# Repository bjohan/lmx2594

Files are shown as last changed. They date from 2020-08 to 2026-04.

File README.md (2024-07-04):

# lmx2594
Test board for lmx2594. The PCB is connected to an Arduino nano which then can be controlled from a PC. The Arduino can be programmed so that the PLL always starts with a certain frequency. It is also possible to change frequency dynamically.

# PCB
Current version of PCB in pcb/lmx2594_v2/

# Arduino sketch
In lmx2594NewSketch/

# Python library commandline tool
In py/ 
```
/lmx2594cmd2.py --help
usage: lmx2594.py [-h] [-f FREQUENCY] [-r REFERENCE] [-mo MASH_ORDER] [-m] [-l] port

Program for controlling lmx2594 pll

positional arguments:
  port                  For instance /dev/ttyUSB0

options:
  -h, --help            show this help message and exit
  -f FREQUENCY, --frequency FREQUENCY
                        Set frequency
  -r REFERENCE, --reference REFERENCE
                        Reference frequency
  -mo MASH_ORDER, --mash-order MASH_ORDER
                        Order of delta sigma
  -m, --macro           Record macro while setting frequency that will be executed at boot. This means that the device will set the specified frequency during power on even without a
                        computer
  -l, --locked          Check lock status

Have fun!
```

Example:

Program arduino so it always starts at 1296MHz with 10MHz reference
```
./lmx2594cmd2.py /dev/ttyUSB0 -r 10e6 -f 1296e6 -m
```

Example:

Set the frequency to 144MHz with 10MHz reference
```
./lmx2594cmd2.py /dev/ttyUSB0 -r 10e6 -f 144e6
```

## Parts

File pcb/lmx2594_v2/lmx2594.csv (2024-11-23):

Source: | /home/bjohan/git_wd/lmx2594/pcb/lmx2594_v2/lmx2594.sch
Date: | lör 23 nov 2024 11:15:43
Tool: | Eeschema 7.0.11+dfsg-1build4
Generator: | /usr/share/kicad/plugins/bom_csv_grouped_by_value_with_fp.py
Component Count: | 108
Ref | Qnty | Value | Cmp name | Footprint | Description | Vendor | DNP
C1, C4, C5, C7, C10, C13, C15 | 7 | 10u | C | Capacitors_SMD:C_1210 | Unpolarized capacitor
C2, C3, C6, C8, C9, C11, C12, C14, C19, C40, C41, C42, C43, C59 | 14 | 100n | C | Capacitors_SMD:C_0603 | Unpolarized capacitor
C16, C21, C22, C23, C24, C25, C32, C35, C38, C44, C45 | 11 | 1u | C | Capacitors_SMD:C_0603 | Unpolarized capacitor
C17, C20, C51, C53 | 4 | 10p | C | Capacitors_SMD:C_0402 | Unpolarized capacitor
C18, C26, C27, C33, C50, C52, C56, C57 | 8 | 100n | C | Capacitors_SMD:C_0402 | Unpolarized capacitor
C28 | 1 | 1.8n | C | Capacitors_SMD:C_0603 | Unpolarized capacitor
C29 | 1 | 0p | C | Capacitors_SMD:C_0603 | Unpolarized capacitor
C30 | 1 | 68n | C | Capacitors_SMD:C_0603 | Unpolarized capacitor
C31 | 1 | 390p | C | Capacitors_SMD:C_0603 | Unpolarized capacitor
C34, C36, C37, C39 | 4 | 10u | C | Capacitors_SMD:C_0603 | Unpolarized capacitor
C46 | 1 | 10u-1000u | C | Capacitors_SMD:C_1210_HandSoldering | Unpolarized capacitor
C55, C58 | 2 | 100p | C | Capacitors_SMD:C_0402 | Unpolarized capacitor
D1, D2, D3 | 3 | LED | LED | LEDs:LED_0805_HandSoldering | Light emitting diode
J1, J2, J4, J5, J7, J9 | 6 | Conn_Coaxial | Conn_Coaxial | sch:sma_endlaunch | coaxial connector (BNC, SMA, SMB, SMC, Cinch/RCA, LEMO, ...)
J3 | 1 | Conn_01x13_Male | Conn_01x13_Male-Connector | Connectors_Molex:Molex_KK-6410-13_13x2.54mm_Straight
L1, L3, L5 | 3 | 33u | L_Core_Ferrite-Device | Inductors_NEOSID:Neosid_Inductor_Ms95
L2, L4 | 2 | 10n | L_Core_Ferrite-Device | Capacitors_SMD:C_0402
L7, L8 | 2 | 18n | L | Capacitors_SMD:C_0402 | Inductor
R1, R2, R6, R7, R10, R15, R24, R25, R26, R27 | 10 | 0 | R | Capacitors_SMD:C_0603 | Resistor
R3, R8 | 2 | 50 | R | Capacitors_SMD:C_0603 | Resistor
R4, R9 | 2 | 150 | R | Capacitors_SMD:C_0603 | Resistor
R5 | 1 | 1k | R | Capacitors_SMD:C_0603 | Resistor
R11, R12, R13, R16, R18, R19, R20, R22 | 8 | 50 | R | Resistors_SMD:R_0402 | Resistor
R14 | 1 | 18 | R | Capacitors_SMD:C_0603 | Resistor
R17, R28, R29 | 3 | 68 | R | Capacitors_SMD:C_0603 | Resistor
R21 | 1 | 100 | R | Capacitors_SMD:C_0603 | Resistor
R23 | 1 | 10K | R | Capacitors_SMD:C_0603 | Resistor
U1 | 1 | LM7809_TO220 | LM7809_TO220 | Package_TO_SOT_THT:TO-220-3_Vertical | Positive 1A 35V Linear Regulator, Fixed Output 9V, TO-220
U2 | 1 | VS_500 | VS_500 | Oscillators:Oscillator_SMD_Fordahl_DFAS1-6pin_14.8x9.1mm
U3 | 1 | lmx254 | lmx254 | Housings_DFN_QFN:Texas_PVQFN-N40
U4 | 1 | L7805 | L7805 | Power_Integrations:TO-220 | Positive 1.5A 35V Linear Regulator, Fixed Output 5V, TO-220/TO-263/TO-252
U5 | 1 | ADP7158 | ADP7158 | Housings_SOIC:SOIC-8-1EP_3.9x4.9mm_Pitch1.27mm
U6, U7 | 2 | GRF3042 | GRF3042 | Housings_DFN_QFN:DFN-6-1EP_2x2mm_Pitch0.5mm

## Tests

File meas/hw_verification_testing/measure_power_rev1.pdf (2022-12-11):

## measure_power

May 23, 2022

[2]: import sys
sys.path.append("gpib_instrument_control/") import lmx2594
import gpib_instrument_control.hp_3478a
import gpib_instrument_control.pm_1038

meter = gpib_instrument_control.hp_3478a.Hp3478A()
pm = gpib_instrument_control.pm_1038.Pm1038(None, meter, None,␣ ↪"pm11-0674_correctionFactors.mat")

lmx = lmx2594.Lmx2594('/dev/ttyUSB0', 320e6)

lmx.enableLockDetect(True)
print("Is locked?", lmx.isLocked()) print(pm.readChannelB(50e6))

Created LMX object wit fosc 320.0 Resetting LMX
Applying config
Is locked: True
Is locked? True
-7.598000000000001

[16]: import numpy as np
import matplotlib.pyplot as plt
import time
%matplotlib inline
plt.rcParams['figure.figsize'] = [15, 10]

def powerSweep(frange):
ampl = []
lmx.setFrequency(frange[0]) time.sleep(1)
for f in frange:
lmx.setFrequency(f)
ampl.append(pm.readChannelB(f)) return ampl

#frange = np.linspace(1e9, 15e9, 30) #plt.plot(frange, ampl)

[18]: frange = np.linspace(10e9, 15e9, 1500) amplRedA = powerSweep(frange) plt.plot(frange, amplRedA, label='redA') plt.grid(True)
plt.legend()
plt.title('Output power vs frequency') plt.ylabel('Output power [dBm]') plt.xlabel('frequency [Hz]')

[18]: Text(0.5, 0, 'frequency [Hz]')

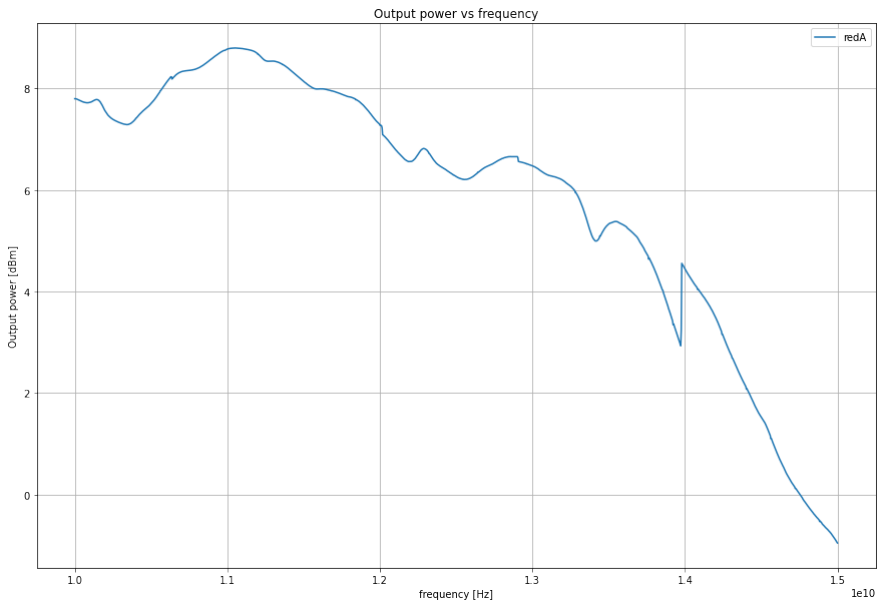
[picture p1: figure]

[20]: frange = np.linspace(10e9, 15e9, 1500) amplRedB = powerSweep(frange) plt.plot(frange, amplRedB, label='redB') plt.grid(True)
plt.legend()
plt.title('Output power vs frequency') plt.ylabel('Output power [dBm]') plt.xlabel('frequency [Hz]')

[20]: Text(0.5, 0, 'frequency [Hz]')

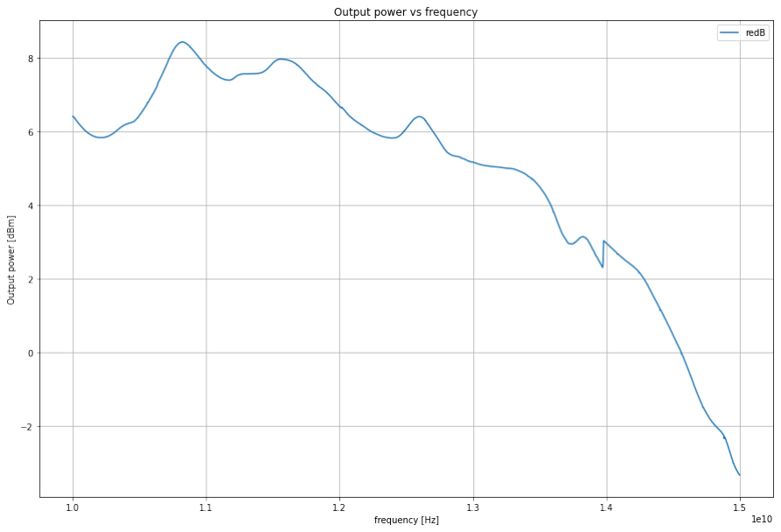
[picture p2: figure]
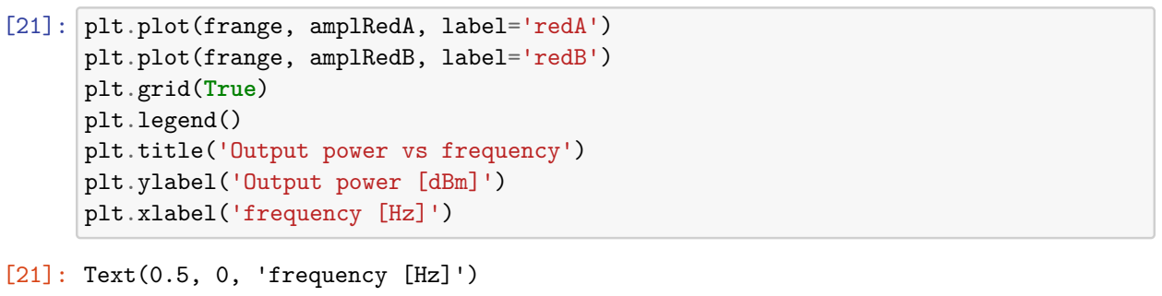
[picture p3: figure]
[21]: plt.plot(frange, amplRedA, label='redA') plt.plot(frange, amplRedB, label='redB') plt.grid(True) plt.legend() plt.title('Output power vs frequency') plt.ylabel('Output power [dBm]') plt.xlabel('frequency [Hz]'); [21]: Text(0.5, 0, 'frequency [Hz]')

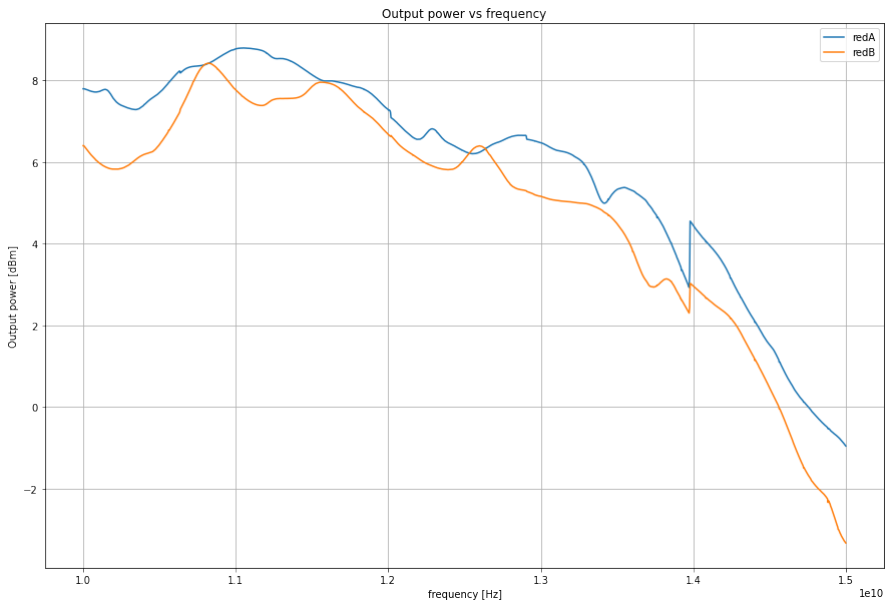
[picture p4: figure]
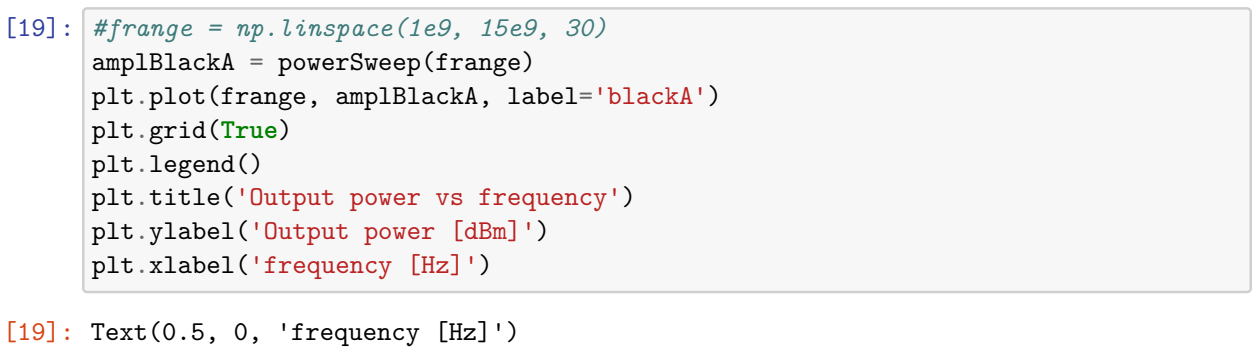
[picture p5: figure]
amplBlackA = powerSweep(frange) plt.plot(frange, amplBlackA, label='blackA') plt.grid(True) plt.legend() plt.title('Output power vs frequency') plt.ylabel('Output power [dBm]') plt.xlabel('frequency [Hz]'); [19]: Text(0.5, 0, 'frequency [Hz]')

[19]: #frange = np.linspace(1e9, 15e9, 30)

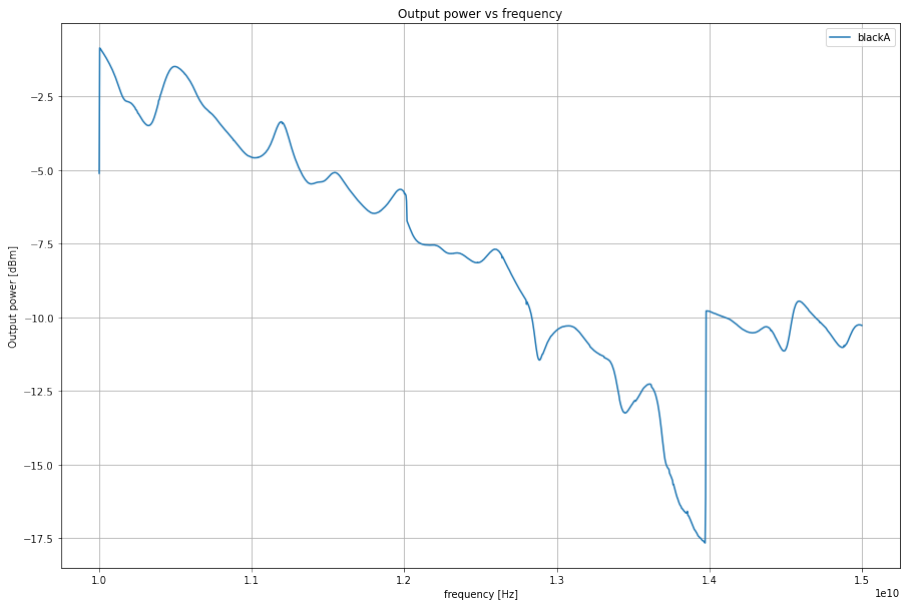
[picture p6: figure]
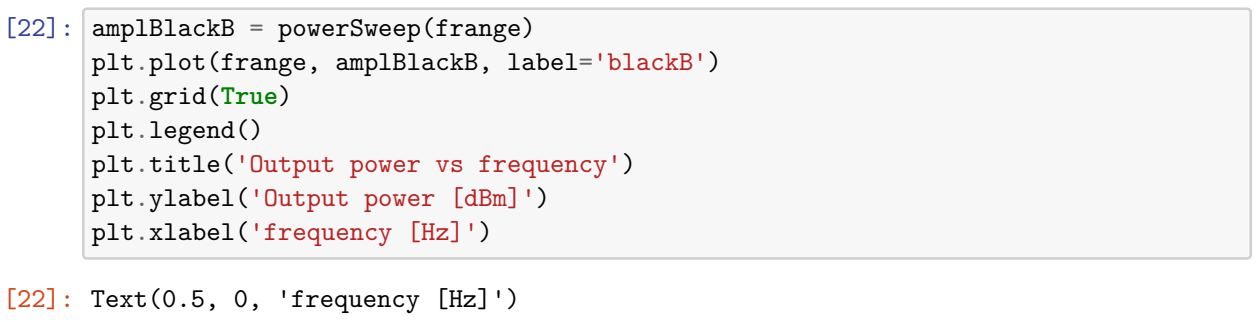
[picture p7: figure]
[22]: amplBlackB = powerSweep(frange) plt.plot(frange, amplBlackB, label='blackB') plt.grid(True) plt.legend() plt.title('Output power vs frequency') plt.ylabel('Output power [dBm]') plt.xlabel('frequency [Hz]'); [22]: Text(0.5, 0, 'frequency [Hz]')

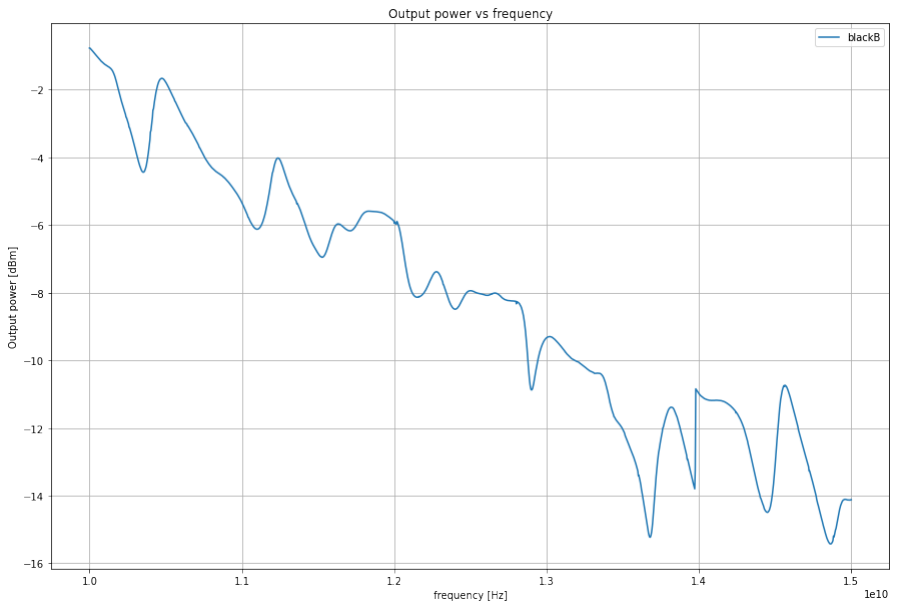
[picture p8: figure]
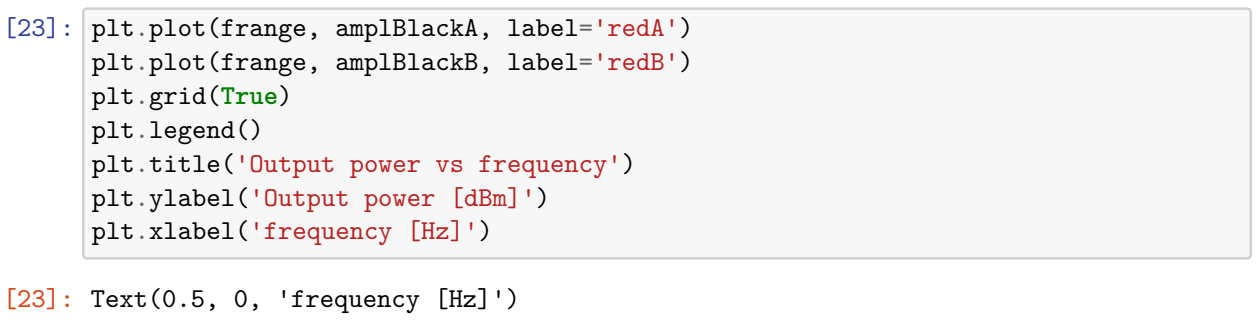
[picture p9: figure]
[23]: plt.plot(frange, amplBlackA, label='redA') plt.plot(frange, amplBlackB, label='redB') plt.grid(True) plt.legend() plt.title('Output power vs frequency') plt.ylabel('Output power [dBm]') plt.xlabel('frequency [Hz]'); [23]: Text(0.5, 0, 'frequency [Hz]')

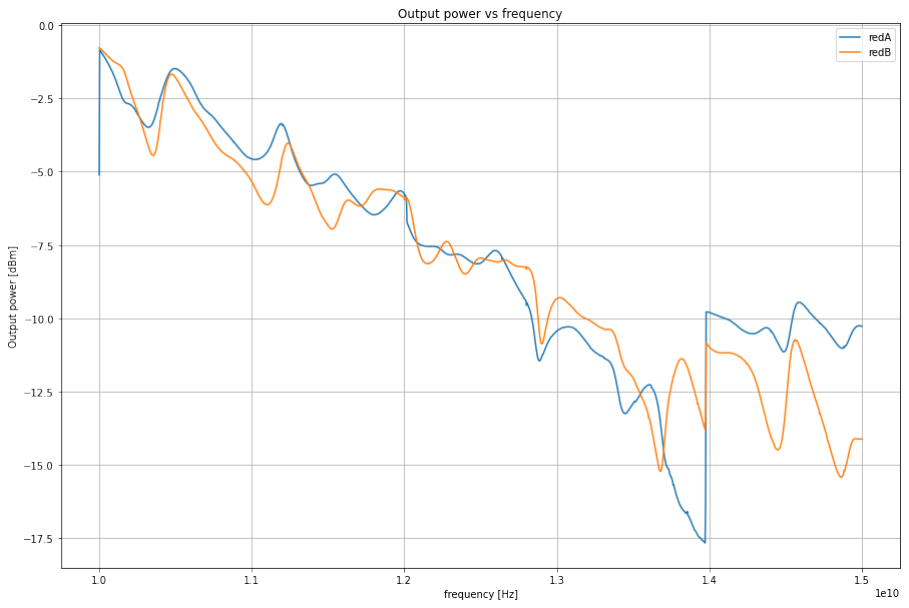
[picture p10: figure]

[25]: import scipy.io as sio

sm = {'f':frange,
'redA': amplRedA,
'redB': amplRedB,
'redA': amplBlackA,
'redB': amplBlackB,
}

sio.savemat('amplitude_data.mat', sm)

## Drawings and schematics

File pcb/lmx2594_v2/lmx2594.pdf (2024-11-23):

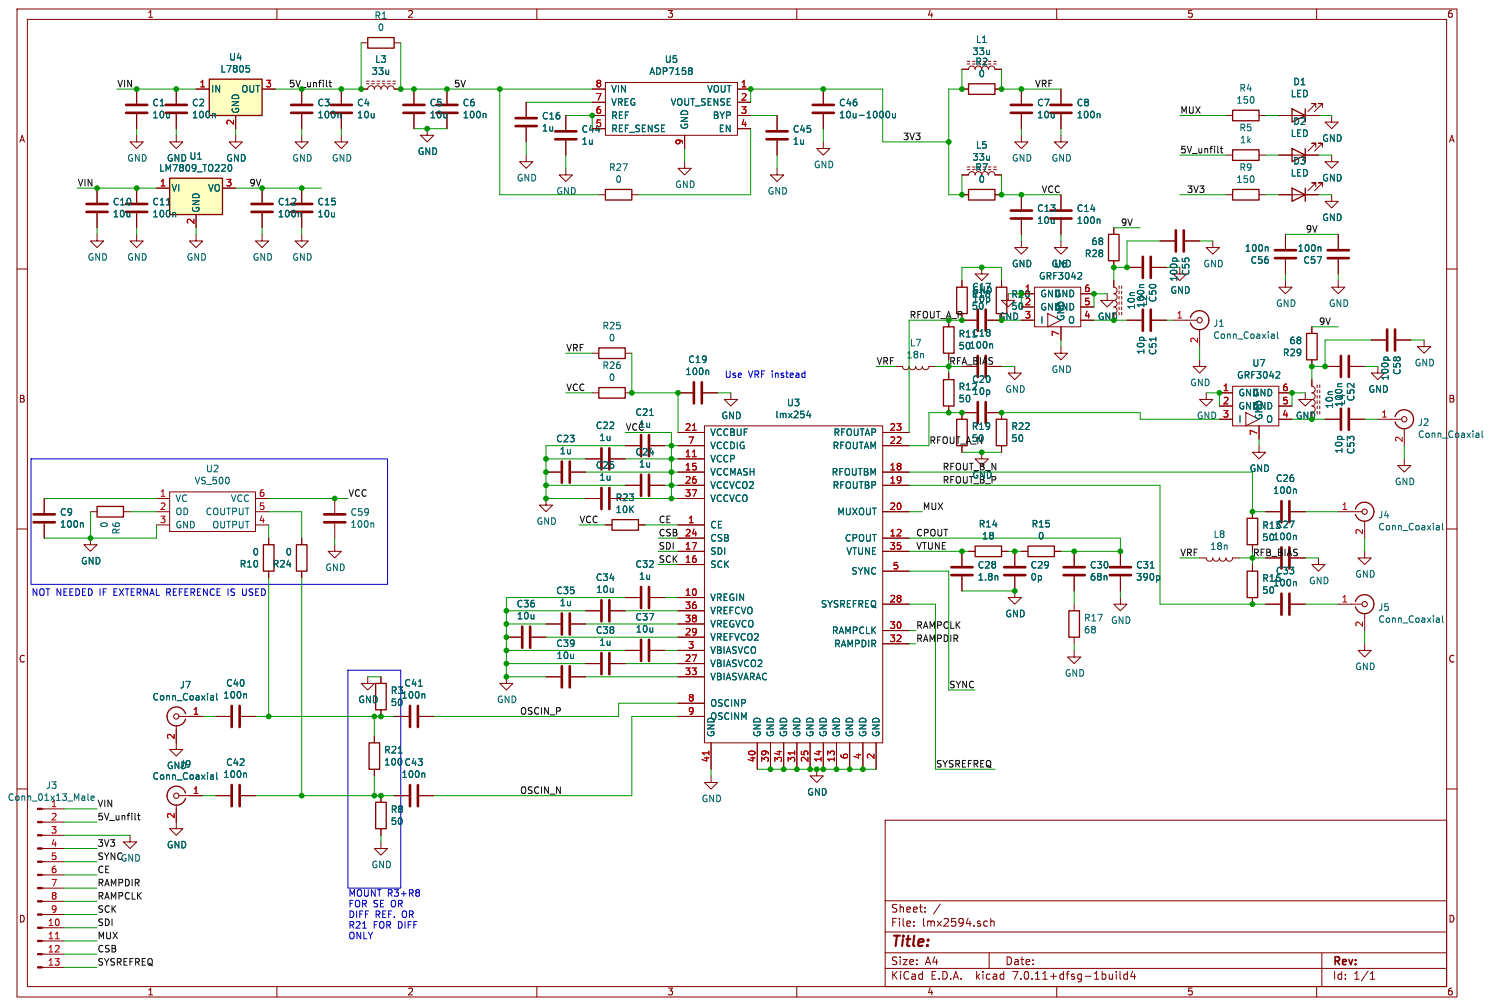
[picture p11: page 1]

2 MUXOUT 20 VCCBUF 21 RFOUTAM 22 RFOUTAP 23 CSB 24 GND 25 VCCVCO2 26 VBIASVCO2 27 SYSREFREQ 28 VREFVCO2 29 VBIASVCO 3 RAMPCLK 30 GND 31 RAMPDIR 32 VBIASVARAC 33 GND 34 VTUNE 35 VREFCVO 36 VCCVCO 37 VREGVCO 38 GND 39 GND

6 VCCDIG 7 OSCINP 8 OSCINM 9 GND

4 GND 40 GND 41 SYNC 5 GND

Id: 1/1 Title: File: lmx2594.sch Sheet: /

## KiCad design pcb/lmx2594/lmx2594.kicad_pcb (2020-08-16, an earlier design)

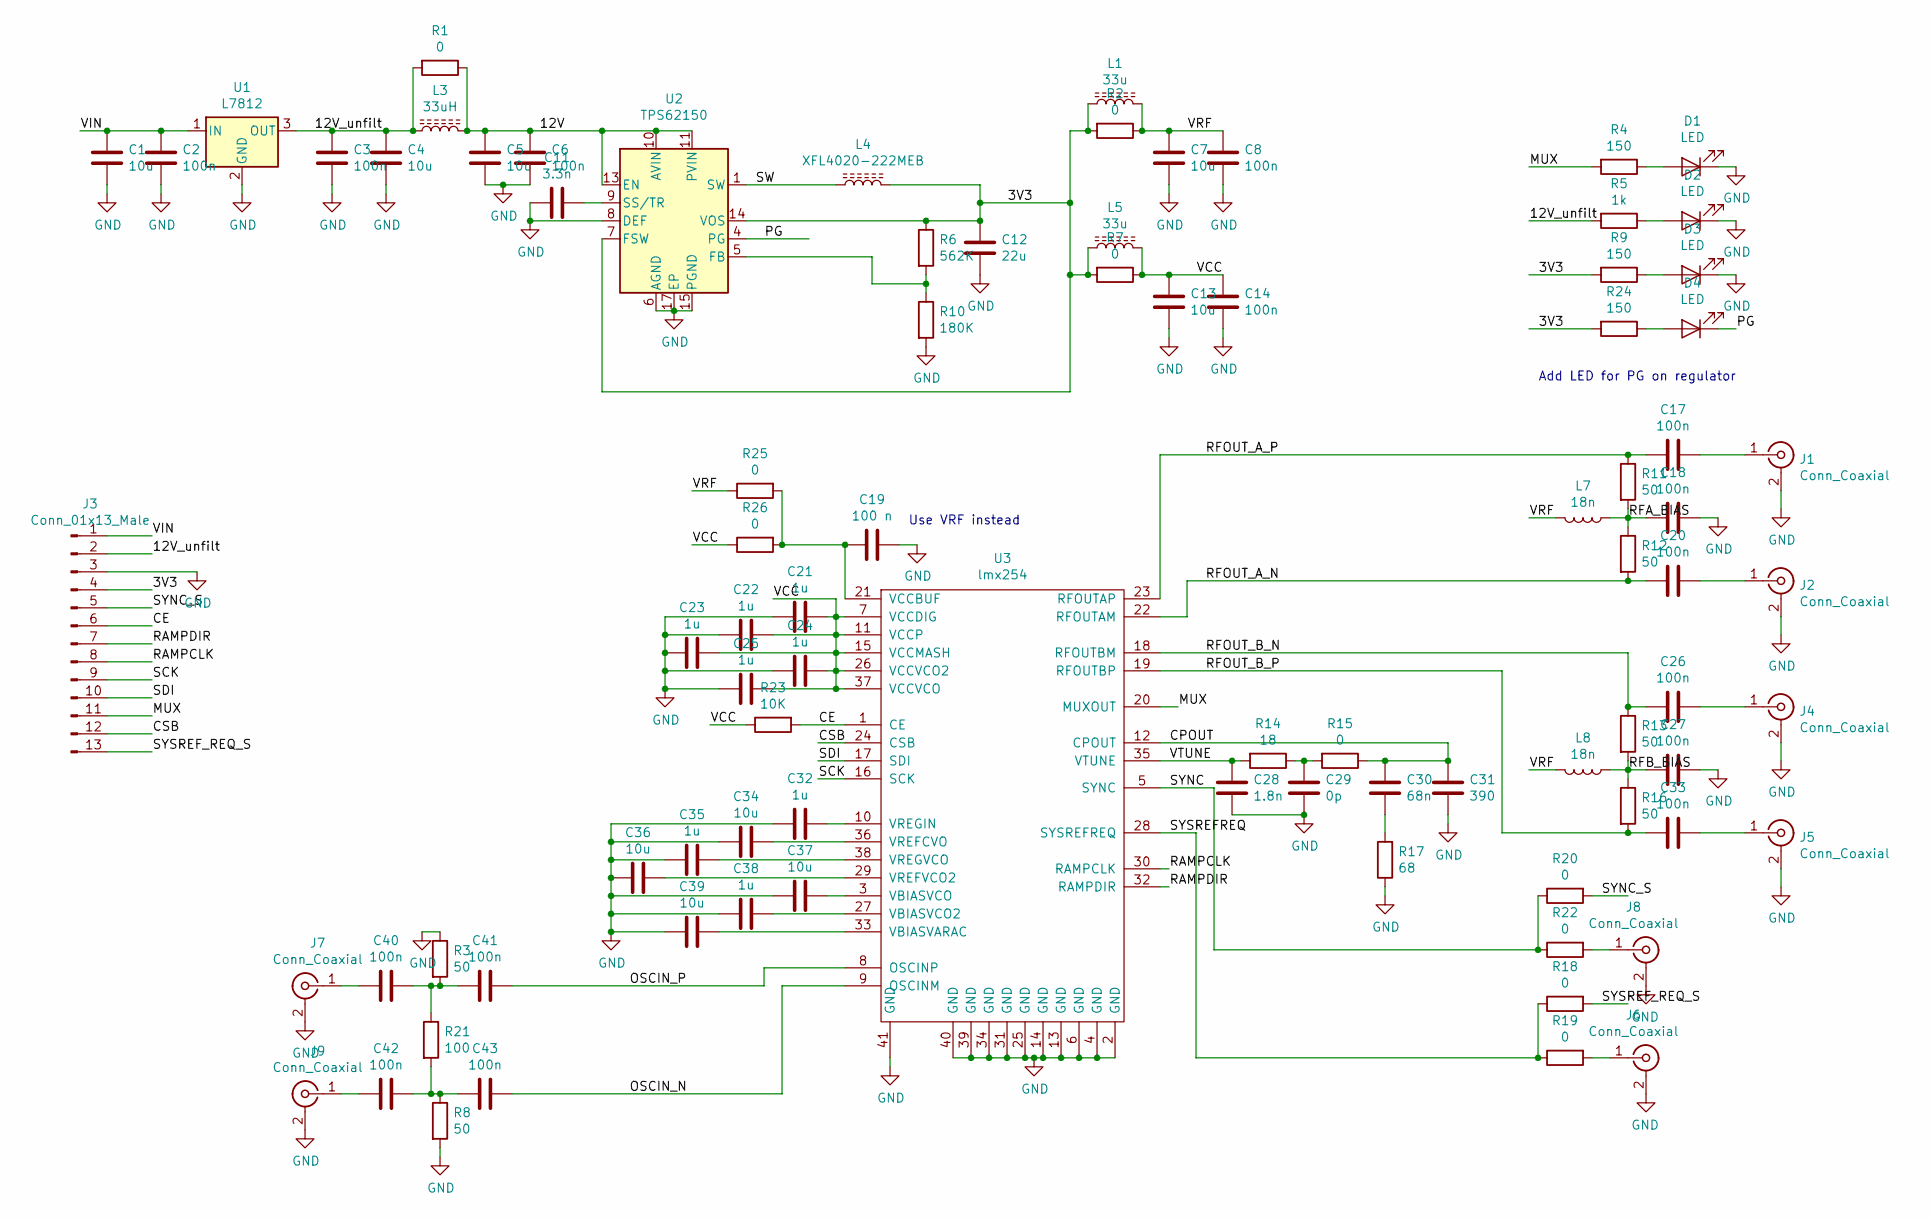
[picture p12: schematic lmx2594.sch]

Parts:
C1, C4, C5: 10u; C_1210_HandSoldering
C2, C3, C6, C8, C14, C17, C18, C20, C26, C27, C33, C40, C41, C42, C43: 100n; C_0603
C7, C13, C34, C36, C37, C39: 10u; C_0603
C11: 3.3n; C_0603
C12: 22u; C_0603
C19: 100 n; C_0603
C21, C22, C23, C24, C25, C32, C35, C38: 1u; C_0603
C28: 1.8n; C_0603
C29: 0p; C_0603
C30: 68n; C_0603
C31: 390; C_0603
D1, D2, D3, D4: LED; LED_0805_HandSoldering
J1, J2, J4, J5, J6, J7, J8, J9: Conn_Coaxial; SMA_THT_Jack_Straight
J3: Conn_01x13_Male; Molex_KK-6410-13_13x2.54mm_Straight
L1, L5: 33u; Neosid_Inductor_Ms95
L3: 33uH; Neosid_Inductor_Ms95
L4: XFL4020-222MEB; Inductor_Wurth_MAPI-4020
L7, L8: 18n; C_0603
R1, R2, R7, R15, R18, R19, R20, R22, R25, R26: 0; C_0603
R3, R8, R11, R12, R13, R16: 50; C_0603
R4, R9, R24: 150; C_0603
R5: 1k; C_0603
R6: 562K; C_0603
R10: 180K; C_0603
R14: 18; C_0603
R17: 68; C_0603
R21: 100; C_0603
R23: 10K; C_0603
U1: L7812; TO-220
U2: TPS62150; QFN-16-1EP_3x3mm_Pitch0.5mm_ThermalVias
U3: lmx254; Texas_PVQFN-N40

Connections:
/3V3: C12.1, J3.4, L1.1, L4.2, L5.1, R2.2, R6.1, R7.2, R9.2, R24.2, U2.7 (FSW), U2.14 (VOS)
/12V: C5.1, C6.1, L3.2, R1.1, U2.10 (AVIN), U2.11 (PVIN), U2.12 (PVIN), U2.13 (EN)
/12V_unfilt: C3.1, C4.1, J3.2, L3.1, R1.2, R5.2, U1.3 (OUT)
/CE: J3.6, R23.2, U3.1 (CE)
/CPOUT: C30.1, C31.1, R15.1, U3.12 (CPOUT)
/CSB: J3.12, U3.24 (CSB)
/MUX: J3.11, R4.2, U3.20 (MUXOUT)
/OSCIN_N: C43.1, U3.9 (OSCINM)
/OSCIN_P: C41.1, U3.8 (OSCINP)
/PG: D4.1 (K), U2.4 (PG)
/RAMPCLK: J3.8, U3.30 (RAMPCLK)
/RAMPDIR: J3.7, U3.32 (RAMPDIR)
/RFA_BIAS: C18.2, L7.1, R11.2, R12.1
/RFB_BIAS: C27.2, L8.1, R13.2, R16.1
/RFOUT_A_N: C20.2, R12.2, U3.22 (RFOUTAM)
/RFOUT_A_P: C17.2, R11.1, U3.23 (RFOUTAP)
/RFOUT_B_N: C26.2, R13.1, U3.18 (RFOUTBM)
/RFOUT_B_P: C33.2, R16.2, U3.19 (RFOUTBP)
/SCK: J3.9, U3.16 (SCK)
/SDI: J3.10, U3.17 (SDI)
/SW: L4.1, U2.1 (SW), U2.2 (SW), U2.3 (SW)
/SYNC: R20.1, R22.1, U3.5 (SYNC)
/SYNC_S: J3.5, R20.2
/SYSREFREQ: R18.1, R19.1, U3.28 (SYSREFREQ)
/SYSREF_REQ_S: J3.13, R18.2
/VCC: C13.1, C14.1, C21.1, C22.1, C23.1, C24.1, C25.1, L5.2, R7.1, R23.1, R26.1, U3.7 (VCCDIG), U3.11 (VCCP), U3.15 (VCCMASH), U3.26 (VCCVCO2), U3.37 (VCCVCO)
/VIN: C1.1, C2.1, J3.1, U1.1 (IN)
/VRF: C7.1, C8.1, L1.2, L7.2, L8.2, R2.1, R25.1
/VTUNE: C28.1, R14.2, U3.35 (VTUNE)
GND: C1.2, C2.2, C3.2, C4.2, C5.2, C6.2, C7.2, C8.2, C11.2, C12.2, C13.2, C14.2, C18.1, C19.1, C21.2, C22.2, C23.2, C24.2, C25.2, C27.1, C28.2, C29.2, C31.2, C32.2, C34.2, C35.2, C36.2, C37.2, C38.2, C39.2, D1.1 (K), D2.1 (K), D3.1 (K), J1.2 (Ext), J2.2 (Ext), J3.3, J4.2 (Ext), J5.2 (Ext), J6.2 (Ext), J7.2 (Ext), J8.2 (Ext), J9.2 (Ext), R3.1, R8.2, R10.2, R17.1, U1.2 (GND), U2.6 (AGND), U2.8 (DEF), U2.15 (PGND), U2.16 (PGND), U2.17 (EP), U3.2 (GND), U3.4 (GND), U3.6 (GND), U3.13 (GND), U3.14 (GND), U3.25 (GND), U3.31 (GND), U3.34 (GND), U3.39 (GND), U3.40 (GND), U3.41 (GND)
unnamed: C11.1, U2.9 (SS/TR)
unnamed: C17.1, J1.1 (In)
unnamed: C19.2, R25.2, R26.2, U3.21 (VCCBUF)
unnamed: C20.1, J2.1 (In)
unnamed: C26.1, J4.1 (In)
unnamed: C29.1, R14.1, R15.2
unnamed: C30.2, R17.2
unnamed: C32.1, U3.10 (VREGIN)
unnamed: C33.1, J5.1 (In)
unnamed: C34.1, U3.36 (VREFCVO)
unnamed: C35.1, U3.38 (VREGVCO)
unnamed: C36.1, U3.29 (VREFVCO2)
unnamed: C37.1, U3.3 (VBIASVCO)
unnamed: C38.1, U3.27 (VBIASVCO2)
unnamed: C39.1, U3.33 (VBIASVARAC)
unnamed: C40.1, C41.2, R3.2, R21.1
unnamed: C40.2, J7.1 (In)
unnamed: C42.1, C43.2, R8.1, R21.2
unnamed: C42.2, J9.1 (In)
unnamed: D1.2 (A), R4.1
unnamed: D2.2 (A), R5.1
unnamed: D3.2 (A), R9.1
unnamed: D4.2 (A), R24.1
unnamed: J6.1 (In), R19.2
unnamed: J8.1 (In), R22.2
unnamed: R6.2, R10.1, U2.5 (FB)

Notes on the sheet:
Add LED for PG on regulator
Use VRF instead

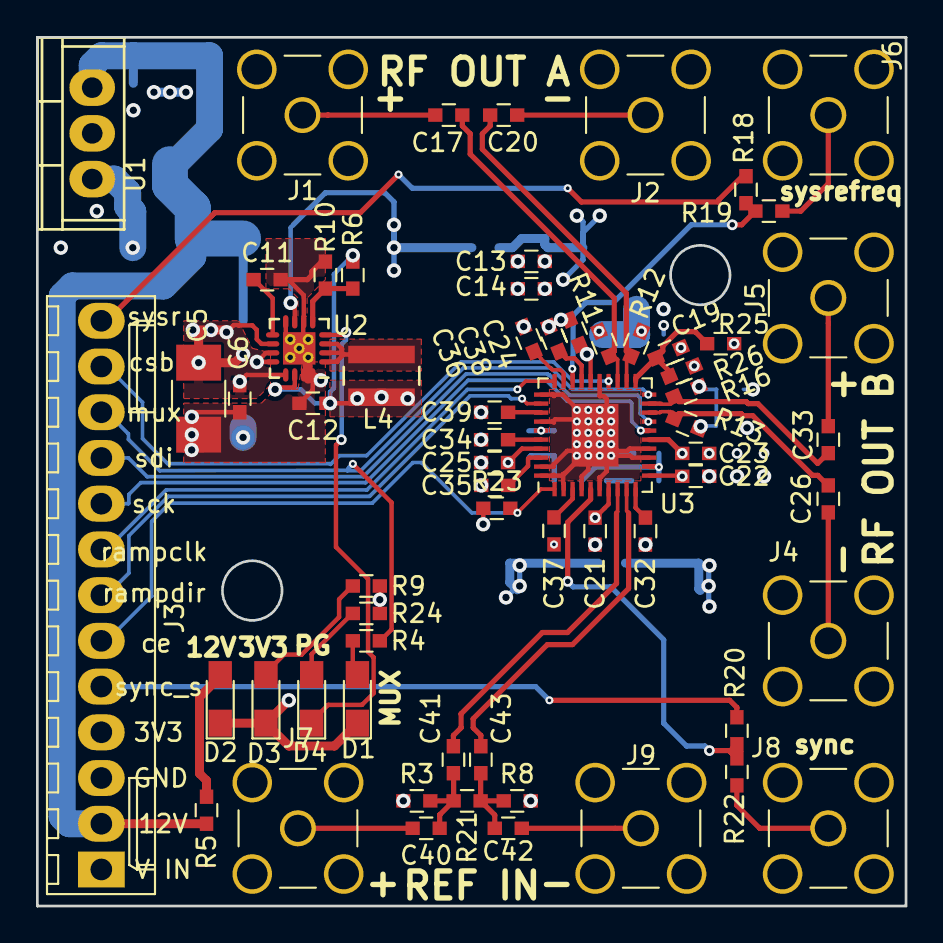
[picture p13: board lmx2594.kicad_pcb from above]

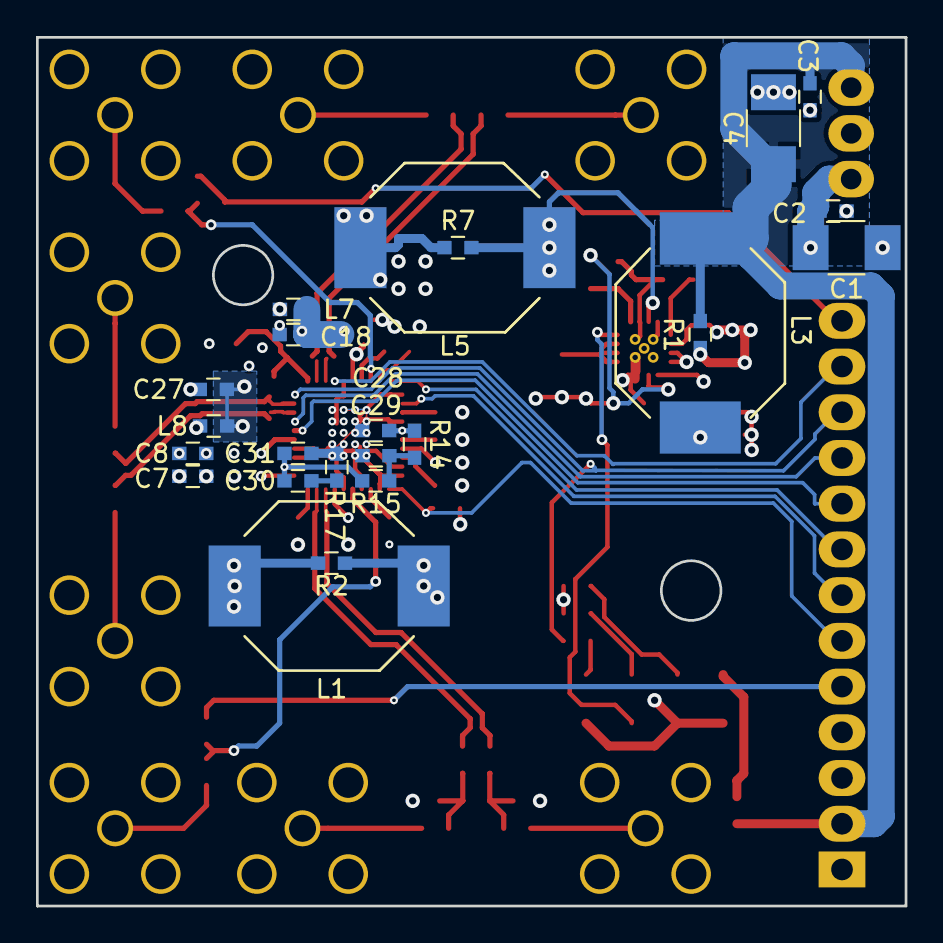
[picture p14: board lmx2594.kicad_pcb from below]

Board: 4 copper layers, 48.3 x 48.3 mm, 87 parts (23 on the bottom side), 56 nets.

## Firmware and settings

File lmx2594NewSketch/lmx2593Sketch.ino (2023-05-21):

#include <EEPROM.h>

bool macro=false;
uint8_t macroPosition=0;



#define SYSREF 5
#define CSB 6
#define MUX 7
#define SDI_DATA_OUT 8
#define SCK 9
#define RAMPCLK 10
#define RAMPDIR 11
#define CE 12
#define SYNC 13

#define REGISTER_R0 0b0010010000010000
#define REGISTER_R1 0b0000100000001000
#define REGISTER_R2 0b0000010100000000
#define REGISTER_R3 0b0000011001000010
#define REGISTER_R4 0b0000000001000011
#define REGISTER_R5 0b0000000011001000
#define REGISTER_R6 0b1100100000000010
#define REGISTER_R7 0b0000000010110010
#define REGISTER_R8 0b0010000000000000
#define REGISTER_R9 0b0000011000000100
#define REGISTER_R10 0b0001000001011000
#define REGISTER_R11 0b0000000000001000
#define REGISTER_R12 0b0101000000000000
#define REGISTER_R13 0b0100000000000000
#define REGISTER_R14 0b0001111000000000
#define REGISTER_R15 0b0000011001001111
#define REGISTER_R16 0b0000000000000000
#define REGISTER_R17 0b0000000000000000
#define REGISTER_R18 0b0000000001100100
#define REGISTER_R19 0b0010011100000000
#define REGISTER_R20 0b1100000001001000
#define REGISTER_R21 0b0000010000000001
#define REGISTER_R22 0b0000000000000001
#define REGISTER_R23 0b0000000001111100
#define REGISTER_R24 0b0000011100011010
#define REGISTER_R25 0b0000110000101011
#define REGISTER_R26 0b0000110110110000
#define REGISTER_R27 0b0000000000000010
#define REGISTER_R28 0b0000010010001000
#define REGISTER_R29 0b0011000110001100
#define REGISTER_R30 0b0011000110001100
#define REGISTER_R31 0b0000001111101100
#define REGISTER_R32 0b0000001110010011
#define REGISTER_R33 0b0001111000100001
#define REGISTER_R34 0b0000000000000000
#define REGISTER_R35 0b0000000000000100
#define REGISTER_R36 0b0000000000000000
#define REGISTER_R37 0b0000000000000100
#define REGISTER_R38 0b0000000000000000
#define REGISTER_R39 0b0000000000000000
#define REGISTER_R40 0b0000000000000000
#define REGISTER_R41 0b0000000000000000
#define REGISTER_R42 0b0000000000000000
#define REGISTER_R43 0b0000000000000000
#define REGISTER_R44 0b0000000000000000
#define REGISTER_R45 0b1100000011000000
#define REGISTER_R46 0b0000011111111100
#define REGISTER_R47 0b0000001100000000
#define REGISTER_R48 0b0000001100000000
#define REGISTER_R49 0b0100000110000000
#define REGISTER_R50 0b0000000000000000
#define REGISTER_R51 0b0000000010000000
#define REGISTER_R52 0b0000100000100000
#define REGISTER_R53 0b0000000000000000
#define REGISTER_R54 0b0000000000000000
#define REGISTER_R55 0b0000000000000000
#define REGISTER_R56 0b0000000000000000
#define REGISTER_R57 0b0000000000100000
#define REGISTER_R58 0b0000000000000001
#define REGISTER_R59 0b0000000000000000
#define REGISTER_R60 0b0000000000000000
#define REGISTER_R61 0b0000000010101000
#define REGISTER_R62 0b0000001100100010
#define REGISTER_R63 0b0000000000000000
#define REGISTER_R64 0b0001001110001000
#define REGISTER_R65 0b0000000000000000
#define REGISTER_R66 0b0000000111110100
#define REGISTER_R67 0b0000000000000000
#define REGISTER_R68 0b0000001111101000
#define REGISTER_R69 0b0000000000000000
#define REGISTER_R70 0b0000000000000000
#define REGISTER_R71 0b0000000000000001
#define REGISTER_R72 0b0000000000000000
#define REGISTER_R73 0b0000000000000000
#define REGISTER_R74 0b0000000000000000
#define REGISTER_R75 0b0000100000000000
#define REGISTER_R76 0b0000000000001100
#define REGISTER_R77 0b0000000000000000
#define REGISTER_R78 0b0000000000000001
#define REGISTER_R79 0b0000000000000000
#define REGISTER_R80 0b0000000000000000
#define REGISTER_R81 0b0000000000000000
#define REGISTER_R82 0b0000000000000000
#define REGISTER_R83 0b0000000000000000
#define REGISTER_R84 0b0000000000000000
#define REGISTER_R85 0b0000000000000000
#define REGISTER_R86 0b0000000000000000
#define REGISTER_R87 0b0000000000000000
#define REGISTER_R88 0b0000000000000000
#define REGISTER_R89 0b0000000000000000
#define REGISTER_R90 0b0000000000000000
#define REGISTER_R91 0b0000000000000000
#define REGISTER_R92 0b0000000000000000
#define REGISTER_R93 0b0000000000000000
#define REGISTER_R94 0b0000000000000000
#define REGISTER_R95 0b0000000000000000
#define REGISTER_R96 0b0000000000000000
#define REGISTER_R97 0b0000100000000000
#define REGISTER_R98 0b0000000000000000
#define REGISTER_R99 0b0000000000000000
#define REGISTER_R100 0b0000000000000000
#define REGISTER_R101 0b0000000000000000
#define REGISTER_R102 0b0000000000000000
#define REGISTER_R103 0b0000000000000000
#define REGISTER_R104 0b0000000000000000
#define REGISTER_R105 0b0000000000000000
#define REGISTER_R106 0b0000000000000000
#define REGISTER_R107 0b0000000000000000
#define REGISTER_R108 0b0000000000000000
#define REGISTER_R109 0b0000000000000000
#define REGISTER_R110 0b0000000000000000
#define REGISTER_R111 0b0000000000000000
#define REGISTER_R112 0b0000000000000000



const PROGMEM uint16_t default_regmap[] {
	REGISTER_R0, REGISTER_R1, REGISTER_R2, REGISTER_R3, REGISTER_R4, REGISTER_R5, REGISTER_R6, REGISTER_R7, 
	REGISTER_R8, REGISTER_R9, REGISTER_R10, REGISTER_R11, REGISTER_R12, REGISTER_R13, REGISTER_R14, REGISTER_R15,
	REGISTER_R16, REGISTER_R17, REGISTER_R18 ,REGISTER_R19, REGISTER_R20, REGISTER_R21, REGISTER_R22, REGISTER_R23,
	REGISTER_R24, REGISTER_R25, REGISTER_R26, REGISTER_R27, REGISTER_R28, REGISTER_R29, REGISTER_R30, REGISTER_R31,
	REGISTER_R32, REGISTER_R33, REGISTER_R34, REGISTER_R35, REGISTER_R36, REGISTER_R37, REGISTER_R38, REGISTER_R39, 
	REGISTER_R40, REGISTER_R41, REGISTER_R42, REGISTER_R43, REGISTER_R44, REGISTER_R45, REGISTER_R46, REGISTER_R47, 
	REGISTER_R48, REGISTER_R49, REGISTER_R50, REGISTER_R51, REGISTER_R52, REGISTER_R53, REGISTER_R54, REGISTER_R55, 
	REGISTER_R56, REGISTER_R57, REGISTER_R58, REGISTER_R59, REGISTER_R60, REGISTER_R61, REGISTER_R62, REGISTER_R63, 
	REGISTER_R64, REGISTER_R65, REGISTER_R66, REGISTER_R67, REGISTER_R68, REGISTER_R69, REGISTER_R70, REGISTER_R71, 
	REGISTER_R72, REGISTER_R73, REGISTER_R74, REGISTER_R75, REGISTER_R76, REGISTER_R77, REGISTER_R78, REGISTER_R79, 
	REGISTER_R80, REGISTER_R81, REGISTER_R82, REGISTER_R83, REGISTER_R84, REGISTER_R85, REGISTER_R86, REGISTER_R87, 
	REGISTER_R88, REGISTER_R89, REGISTER_R90, REGISTER_R91, REGISTER_R92, REGISTER_R93, REGISTER_R94, REGISTER_R95, 
	REGISTER_R96, REGISTER_R97, REGISTER_R98, REGISTER_R99, REGISTER_R100, REGISTER_R101, REGISTER_R102, REGISTER_R103, 
	REGISTER_R104, REGISTER_R105, REGISTER_R106, REGISTER_R107, REGISTER_R108, REGISTER_R109, REGISTER_R110, REGISTER_R111, 
	REGISTER_R112
};	


void writeBits(uint32_t word, uint8_t nbits)
{
	//Serial.print(nbits);
	//Serial.print(" ");
	//Serial.println(word, HEX);
	//Serial.print(" ");
	for(uint32_t b = nbits ; b > 0 ; b--){
		digitalWrite(SCK, LOW);
		if(word & 0x80000000){
			digitalWrite(SDI_DATA_OUT, HIGH);
			//Serial.print("1");
		}
		else{
			digitalWrite(SDI_DATA_OUT, LOW);
			//Serial.print("0");
		}
		digitalWrite(SCK, HIGH);
		word <<= 1;
	}
}

uint16_t readBits(uint8_t nbits)
{
	uint16_t data;
	for(uint32_t b = nbits ; b > 0 ; b--){
		digitalWrite(SCK, LOW);
		data <<= 1;
		data |= digitalRead(MUX);
		digitalWrite(SCK, HIGH);
	}
	return data;
}



void sendWord(uint32_t word)
{
	digitalWrite(CSB, LOW);
	writeBits(word, 24);
	digitalWrite(SCK, LOW);
	digitalWrite(CSB, HIGH);
	digitalWrite(SDI_DATA_OUT, HIGH);
}

uint16_t receiveWord(uint32_t word){
	uint16_t d;
	digitalWrite(CSB, LOW);
	writeBits(word, 8);
	d = readBits(16);
	digitalWrite(SCK, LOW);
	digitalWrite(CSB, HIGH);
	digitalWrite(SDI_DATA_OUT, HIGH);
	return d;
}

uint16_t readRegister(uint32_t addr){
	addr &= 0x7F;
	addr |= 0x80;
	return receiveWord(addr<<24);
}

void writeRegister(uint32_t addr, uint32_t data){
	addr &= 0x7F;
	data &= 0xFFFF;
	sendWord(addr<<24|data<<8);
}

void init_registers(){
	for(int i = 112 ; i >= 0 ; i--) writeRegister(i, default_regmap[i]);
}





void replayMacro(){
	uint8_t nm=EEPROM.read(0);
	Serial.print("Replaying macro consisting of ");
	Serial.print(nm);
	Serial.println(" writes");
	if(nm == 0xFF){
		Serial.println("Nonexistant macro, exiting");
		return;
	}
	for(int i = 0 ; i < nm ; i++){
		uint32_t sw;
		EEPROM.get(1+i*4, sw);
		Serial.print("Macro ");
		Serial.print(i);
		Serial.print(" value ");
		Serial.println(sw);
		sendWord(sw);
	}
}




void setup() {                
	Serial.begin(115200);
	// initialize the digital pin as an output.
	pinMode(SYSREF, OUTPUT);
	pinMode(CSB, OUTPUT);
	pinMode(MUX, INPUT);
	pinMode(SDI_DATA_OUT, OUTPUT);
	pinMode(SCK, OUTPUT);
	pinMode(RAMPCLK, OUTPUT);
	pinMode(RAMPDIR, OUTPUT);
	pinMode(CE, OUTPUT);
	pinMode(SYNC, OUTPUT);
	pinMode(A0, OUTPUT);
	pinMode(A1, OUTPUT);
	pinMode(A2, OUTPUT);
	pinMode(A3, OUTPUT);
	digitalWrite(CSB, HIGH);
	Serial.println("CE LOW");
	digitalWrite(CE, LOW);
	delay(50);
	Serial.println("CE HIGH");
	digitalWrite(CE, HIGH);
	delay(50);
	Serial.println("SPI RST");
	//writeRegister(0, 2);
	//delay(100);
	//writeRegister(0, 0);
	Serial.println("SPI RST DIS");
	//init_registers();
	replayMacro();
	Serial.println("READY");
	
}

uint8_t copyTok(char *dst, char *src, int8_t n){
	for(;*src!='\0'; src++){
		if(*src == ' ') n--;
		else if(n == 0) *dst++=*src;
		if(n < 0 || (n==0 && *(src+1) =='\0')){
			*dst='\0'; 
			return 0;
		}
	}
	return -1;
}


void commandWriteRegister(char *cmdstr){
	uint32_t sw;
	uint32_t addr;
	uint32_t value;	
	char tokbuf[32];
	if(copyTok(tokbuf, cmdstr, 1)){
		Serial.println("First argument must be address");
	}
	addr=atoi(tokbuf);
	if(copyTok(tokbuf, cmdstr, 2)){
		Serial.println("Second argument must be value");
	}
	value=atol(tokbuf);
	/*Serial.println(cmdstr);
	Serial.print("Writing ");
	Serial.print(value);
	Serial.print(" to ");
	Serial.println(addr);*/

	addr &= 0x7F;
	value &= 0xFFFF;
	sw=addr<<24|value<<8;
	//uint32_t sw=(addr&0xF)|((value<<4)&0xFFFFFFF0);
	sendWord(sw);
	
	if(macro){
		EEPROM.put(4*macroPosition+1, sw);
		macroPosition++;
	}
}

void commandReadRegister(char *cmdstr){
	uint32_t addr;
	char tokbuf[32];
	if(copyTok(tokbuf, cmdstr, 1)){
		Serial.println("First argument must be address");
	}
	addr=atoi(tokbuf);
	Serial.print("Read: "); Serial.print(readRegister(addr)); Serial.print(" From register address: "); Serial.println(addr);
}

void commandEnable(char *cmdstr){
	uint8_t enable;
	char tokbuf[32];
	if(copyTok(tokbuf, cmdstr, 1)){
		Serial.println("Firt argument must be 0 to disable or nonzero to enable");
	}
	enable=atoi(tokbuf);
	if(enable){
		pinMode(CE, INPUT);
		digitalWrite(CE, HIGH);
		Serial.println("Chip enabled");
	}else{
		pinMode(CE, OUTPUT);
		digitalWrite(CE, LOW);
		Serial.println("Chip disabled");
	}	
}

void commandMacroRecord(char *cmdstr){
	uint8_t enable;
	char tokbuf[32];
	if(copyTok(tokbuf, cmdstr, 1)){
		Serial.println("First argument must be 0 to finish recording or nonzero to start");
	}
	enable=atoi(tokbuf);
	if(enable){
		if(not macro){
			macro=true;
			macroPosition=0;
			Serial.println("Macro enabled");
		} else {
			Serial.println("Macro was already enabled");
		}
	}else{
		if(macro){
			macro=false;
			EEPROM.write(0, macroPosition);
			macroPosition=0;
			Serial.println("Macro disabled");
		} else {
			Serial.println("macro was already disabled");
		}
	}	

}

void commandReboot(char *cmdstr){
	Serial.println("toggling CE");
	pinMode(CE, OUTPUT);
	digitalWrite(CE, LOW);
	delay(100);
	digitalWrite(CE, HIGH);
	pinMode(CE, INPUT);
	Serial.println("SPI RST");
	writeRegister(0, 2);
	delay(100);
	writeRegister(0, 0);
	Serial.println("SPI RST DIS");
	init_registers();
	replayMacro();

}

void commandOutput(char *cmdstr){
	Serial.print("PLL Output ");
	Serial.println(digitalRead(MUX));
}
void commandGpio(char *cmdstr){
	uint8_t p;
	char tokbuf[32];
	if(copyTok(tokbuf, cmdstr, 1)){
		Serial.println("First argument must be decimal number representing the bit pattern to be output");
	}
	p=atoi(tokbuf);
	digitalWrite(A0, p&0x01);
	digitalWrite(A1, p&0x02);
	digitalWrite(A2, p&0x04);
	digitalWrite(A3, p&0x08);
}


void executeCommand(char* cmdstr){
	char tokbuf[32];
	if(copyTok(tokbuf, cmdstr, 0) == 0){
		switch(tokbuf[0]){
			case 'W':
			case 'w':
				commandWriteRegister(cmdstr);
				break;
			case 'R':
			case 'r':
				commandReadRegister(cmdstr);
				break;

			case 'E':
			case 'e':
				commandEnable(cmdstr);
				break;

			case 'M':
			case 'm':
				commandMacroRecord(cmdstr);
				break;

			case 'B':
			case 'b':
				commandReboot(cmdstr);
				break;

			case 'O':
			case 'o':
				commandOutput(cmdstr);
				break;
			case 'G':
			case 'g':
				commandGpio(cmdstr);
				break;
			default:
				Serial.print("Unrecognized command ");
				Serial.println(cmdstr);
			


		}
	}
	
}




void loop() {
	char d;
	static char cmd[32];
	static uint8_t cp=0;
	if(Serial.available()){
		d=Serial.read();
		if(d=='\r' ||  d== '\n'){
			cmd[cp]='\0';
			executeCommand(cmd);
			Serial.println("DONE");
			cp=0;
		} else {
			if(cp < 15){
				cmd[cp++]=d;
			} else {
				cmd[0]='\0';
				Serial.println("Command too long. Max 15 bytes. Press enter and enter new command");
			} 
		}
	}
}

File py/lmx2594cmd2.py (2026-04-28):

#!/usr/bin/python3
import serial
import sys
import time
import numpy as np
import tqdm
import mpmath as mp
import math 
import fractions
mp.mp.dps=100
import default_config

class Lmx2594():
    
    chdivs = [2, 4, 6, 8, 12, 16, 24, 32, 48, 64, 72, 96, 128, 192, 256, 384, 512, 768]
    registerMap = {
        0: {"RAMP_EN": [15], "VCO_PHASE_SYNC": [14], "OUT_MUTE": [9], "FCAL_HPFD_ADJ":range(7,9), "FCAL_LPFD_ADJ":range(5,7), "FCAL_EN": [3], "MUX_OUT_LD_SEL":[2], "RESET":[1], "POWERDOWN":[0]},
        1: {"CAL_CLK_DIV":[0, 1, 2]},
        4: {"ACAL_CMP_DLY":range(8, 16)},
        7: {"OUT_FORCE":[14]},
        8: {"VCO_DACISET_FORCE":[14], "VCO_CAPCTRL_FORCE":[11]},
        9: {"OSC_2X":[12]},
        10: {"MULT":range(7,12)},
        11: {"PLL_R":range(4, 12)},
        12: {"PLL_R_PRE":range(0, 12)},
        14: {"CPG":range(4, 8)},
        16: {"VCO_DACISET":range(0, 9)},
        17: {"VCO_DACISET_STRT":range(0, 9)},
        19: {"VCP_CAPCTRL":range(0,8)},
        20: {"VCO_SEL":range(11, 14), "VCO_SEL_FORCE": [10]},
        31: {"CHDIV_DIV2":[14]},
        34: {"PLL_N_18_TO_16":range(0, 4)},
        36: {"PLL_N_15_TO_0":range(0, 16)},
        37: {"MASH_SEED_EN":[15], "PFD_DLY_SEL":range(8, 14)},
        38: {"PLL_DEN_31_TO_16":range(0, 16)},
        39: {"PLL_DEN_15_TO_0":range(0, 16)},
        40: {"MASH_SEED_31_TO_16":range(0, 16)},
        41: {"MASH_SEED_15_TO_0":range(0, 16)},
        42: {"PLL_NUM_31_TO_16":range(0, 16)},
        43: {"PLL_NUM_15_TO_0":range(0, 16)},
        44: {"OUTA_PWR":range(8,14), "OUTB_PD":[7], "OUTA_PD":[6], "MASH_RESET_N":[5], "MASH_ORDER":range(0, 4)},
        45: {"OUTA_MUX":range(11, 13), "OUT_ISET":range(9, 11), "OUTB_PWR":range(0, 6)},
        46: {"OUTB_MUX":range(0, 3)},
        58: {"INPIN_IGNORE":[15], "INPIN_HYST":[14], "INPIN_LVL":range(12, 14), "INPIN_FMT":range(9, 12)},
        59: {"LD_TYPE":[0]},
        60: {"LD_DLY":range(0, 16)},
        69: {"MASH_RST_COUNT_31_TO_16":range(0, 16)},
        70: {"MASH_RST_COUNT_15_TO_0":range(0, 16)},
        75: {"CHDIV": range(6, 11)},
        #ignoring sysref and ramping
        110: {"rb_LD_VTUNE":range(9, 11), "rb_VCO_SEL":range(5,8)},
        111: {"rb_VCO_CAPCTRL":range(0, 8)},
        112: {"rb_VCO_DACISET":range(0, 9)},
        }


    def __init__(self, port, fosc=100e6, mash_order=3, timeout=5, macro=False):
        self.shadowMap={}
        if isinstance(port, str):
            self.d=serial.Serial(port, 115200, timeout=timeout);
        else:
            self.d=port

        print("Waiting for LMX2594 to boot");
        msg = self.readOutput(finalToken=b'READY');
        print("Booted successfully");

        if macro:
            print(self.macro(True).decode('ascii').strip())
        self.fosc=fosc
        self.mash_order = mash_order


        print("Created LMX object wit fosc", fosc/1e6)
        self.initialize()
        #self.setField('OSC_2X', 0)
        print("FPD is %f MHz"%(self.getFpd()/1e6))
   

    def write(self, cmd):
        if len(cmd)>15:
            raise ValueError("Command is too long, 16 digits is the max");
        self.d.write(cmd+b'\n')


    def readOutput(self, finalToken=b'DONE\r\n'):
        o=b'';
        while True:
            d=self.d.read(1)
            if len(d) == 0:
                raise Exception("Did not get expected response before timeout. Expected to get %s in \"%s\""%(finalToken, o))
            o+=d;
            if finalToken in o:
                return o[0:-len(finalToken)];

    def query(self, cmd):
        self.write(cmd);
        return self.readOutput()

    def macro(self, state):
        if state:
            return self.query(b"M 1");
        else:
            return self.query(b"M 0");

    def writeRegister(self, addr, value):
        cmdstr=b"W %d %d"%(addr, value)
        self.query(cmdstr)
        self.shadowMap[addr]=value


    def readRegister(self, addr, shadow=True):
        if shadow and addr in self.shadowMap:
            return self.shadowMap[addr]
        cmdstr=b'R %d'%(addr);
        resp=self.query(cmdstr).decode('ascii').split(': ')[1].split(' ')[0]
        print(resp)
        return int(resp)
    

    def locked(self):
        d=self.query(b'O')
        d=d.strip()
        s=d.split(b"PLL Output")[-1].strip()
        return s==b'1'


    def chipEnable(self, state):
        if state:
            self.query(b'E 1')
        else:
            self.query(b'E 0')

    def spiReset(self):
        self.writeRegister(0, 2);
        self.writeRegister(0, 0);

    def reset(self):
        self.chipEnable(False)
        self.chipEnable(True)
        self.spiReset()

    def initialize(self):
        #print("Resetting LMX")
        #print(self.readRegister(9))
        self.reset()
        #print(self.readRegister(9))
        #print("Applying config")
        #self.applyConfig('10GOut320MRef.txt')
        self.applyDefaultConfig()
        self.writeRegister(0, 0)
        self.setupReferencePath()
        self.setField('OUTB_PD', 0)
        self.setField('OUTA_MUX', 1)
        self.setField('OUTB_MUX', 1)
        self.setField('MASH_ORDER', self.mash_order)
        self.setField('OUTA_PWR', 3)
        self.setField('OUTB_PWR', 3)
        time.sleep(0.1)
        #self.setFrequency(10e9)
        time.sleep(0.1)
        self.enableLockDetect(True)
        #print("Is locked: ", self.isLocked())
        

    def setupReferencePath(self):
        ref=self.fosc
        #if ref < 200e6 and ref > 20e6:
        #    self.setField('OSC_2X',1)
        #    ref=ref*2
        #else:
        self.setField('OSC_2X', 0)
        
        if ref > 250e6:
            div=int(ref/250.0e6+1)
        else: 
            div=1
        #print("PRE DIVIDER", div)
        self.setField('PLL_R_PRE', div)
        ref=ref/div

        if ref<250e6/3:
            mul=int(250.0e6/ref+1)
            if mul > 7:
                mul = 7
        else:
            mul=1

        #print("REF MULT", mul)
        self.setField('MULT', mul)
        ref=ref*mul

        self.setField('PLL_R', 1)
        if ref != self.getFpd():
            raise Exception("ERROR in setup reference path. expected %f, got %f"%(ref, self.getFpd()))

        self.setField('CAL_CLK_DIV', 3)

    def printConfig(self):
        for r in self.registerMap:
            fs=self.registerMap[r].keys();
            for f in fs:
                print(f, self.getField(f))

    def applyConfig(self, fn):
        a = open(fn)
        t = a.read()
        for l in t.splitlines():
            r = l.split("0x")[-1]
            a = int(r[0:2],16)
            v = int(r[2:], 16)
            self.writeRegister(a, v)

    def applyDefaultConfig(self):
        addrs = default_config.conf.keys();
        for a in addrs:
            self.writeRegister(a, default_config.conf[a])

    def enableLockDetect(self, state):
        if state:
            self.writeRegister(0, self.readRegister(0)|0x4)
        else:
            self.writeRegister(0, self.readRegister(0)&(0xFFFF-0x4))
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

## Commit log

2019-05-04 schematic done, started placing components
    [lmx2594.kicad_pcb, lmx2594.sch]
2019-05-05 More work on layout
    [lmx2594.kicad_pcb, lmx2594.sch]
2019-05-05 All signals routed DRC pass but needs to be tidied up
    [lmx2594.kicad_pcb]
2019-05-05 Layout sort is probably done, can make something nicer with powerplanes but i do not think it is needed. Silkscreen must also be fixed
    [lmx2594.kicad_pcb, lmx2594.sch]
2019-05-06 Added single ended terminations to osci
    [lmx2594.kicad_pcb, lmx2594.sch]
2019-05-06 Tidying up a bit and added pullup on CE
    [lmx2594.kicad_pcb, lmx2594.sch]
2019-05-06 More review of schematic
    [lmx2594.sch]
2019-06-07 Review, fixed vbuf and added pg led
    [lmx2594.kicad_pcb, lmx2594.sch]
2019-06-07 additional fixes to silkscreen
    [lmx2594.kicad_pcb]
2019-12-10 Fixed diff pair impedance
    [lmx2594.kicad_pcb]
2020-08-16 added v2
    [lmx2594-B.Cu.gbr, lmx2594-B.Mask.gbr, lmx2594-B.Paste.gbr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]
2022-11-22 Added new arduino FW
2022-11-22 cleaned up some prints
2022-11-23 Removed some more spurious prints
2022-12-12 Added smal wrapper for yig filter class so that partially populated board can be used to generate high resolution DC voltages
2022-12-13 Tested voltage generator
2022-12-18 Added some measurements of sweeper frequency and power level in preparation of detector testing
2022-12-19 Added measurement data for modeling test voltage generator
2023-05-03 Added plot and bom
    [lmx2594.csv]
2023-05-20 Added gitignore and removed prints, fixed bug for output power
    [lmx2594cmd2.py]
2023-05-21 Added gpio-support to control external relays. Removed old code, made commandbuffer lagerger
2023-05-21 Removed prints and set mux to correct values
    [lmx2594cmd2.py]
2024-11-23 Updated schematic to KiCad 7.0. Note that layout etc has not been updated yet
    [lmx2594.csv]
2026-04-28 Quick fix for lock failure with high reference input
    [lmx2594cmd2.py]
